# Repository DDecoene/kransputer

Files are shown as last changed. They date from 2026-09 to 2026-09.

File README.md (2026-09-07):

# kransputer

## What Kransputer is

Kransputer is a working computer built from a few thousand discrete CMOS
transistors — a machine on the scale of an Intel 4004, but made of parts you can
hold — designed to grow into a multiprocessor: one core, then a ring of up to
eight, passing messages the way INMOS's Transputer did. It exists to be
understood and rebuilt, by a person, a class or a hackerspace. Not to be sold.

## Why it looks the way it does

One decision forces everything else: CMOS. Almost every discrete-transistor
computer ever built is NMOS and burns about a watt standing still. CMOS costs
twice the transistors but makes power scale with clock rate instead — turn the
clock down and the machine sips. Staying inside a small transistor budget is why
the design is stripped to the bone:

- **One instruction** — subleq only, so there is no decoder. The instruction set
  lives in the assembler as macros.
- **A few bits at a time** — a serial datapath, so the arithmetic unit is a
  handful of adders. You pay in clock cycles, which are cheap.
- **No bus** — memory, display and input all speak SPI over four wires. No
  address bus, no data bus.

On this machine, talking to the core next door is cheaper than reading your own
memory. That is why the ring is the point, not an afterthought.

## How it gets built — from the ground up

The architecture is settled on paper: a SUBLEQ core with a serial datapath and
SPI links, meant to grow into a message-passing ring. What is deliberate is the
direction of the work. Instead of proving the whole machine on an FPGA before
touching a soldering iron, Kransputer is built upward from real gates, one
module at a time.

1. **Gates** — small PCBs, each a fistful of MOSFETs forming one logic function
   (NAND, NOR, NOT …), that plug into a breadboard and share a common bus. This
   is the layer built so far.
2. **Blocks** — those gates wired into the units the design calls for: the serial
   adder that is the whole ALU, the registers, the subleq sequencer and bit
   counter, the SPI interface to memory, the four-wire link to the next core.
   Each block is first modelled in structural Verilog — gate for gate, built
   from the same NAND/NOR/NOT cells as the boards — and checked in simulation,
   then built physically on breadboards.
3. **A core** — one complete processor, assembled from the blocks.
4. **A ring** — the core replicated and connected: two, then four, then eight,
   blocking on the links for synchronisation.

The structural model is the reference: the same stimulus into the simulation and
into the breadboard must give the same result, or the block is wrong.

## Status

The gate boards are drawn but **not yet routed** — schematics and rough
placement are done, copper is not. Work right now is on the first blocks in
structural Verilog, which land here soon. Once those hold up in simulation the
boards get routed and finished for a first self-ordered run, with build notes
and other material alongside.

## This repository

Discrete-logic building blocks for the kransputer — the **Gates** layer above.
Each module is a small PCB that plugs into a breadboard on two opposite edge
headers carrying an identical 16-pin pass-through bus, so modules can sit side by
side across one or more breadboards and be wired together into larger logic.

## Boards

| TARGET | Board |
|---|---|
| `nand` | 4x discrete static-CMOS 2-input NAND |
| `nor` | 4x discrete static-CMOS 2-input NOR |
| `not` | 6x discrete static-CMOS inverter |
| `indicator` | 12-channel buffered bus LED indicator |

Logic FETs are AO3400A (N-channel) / AO3401A (P-channel) in SOT-23.

The logic boards carry **no** indicator parts. Every node is on the bus; the
indicator board buffers each signal with a single AO3400A in common source (its
gate is high-impedance, so the logic net is not loaded) that sinks an LED fed
from the indicator board's own VDD rail. **LED lit = logic 1.** Watching the
machine therefore does not sag the logic levels.

## Bus pinout

Both edge headers (`J1`, `J2`) carry the same 16 pins, wired 1:1, so any signal
is reachable from either edge. Framing is fixed: pin 1 = VDD, pin 2 = GND,
pins 3–14 carry the 12 signal nets the board drives, pins 15/16 are the
edge-to-edge spares (`BUS_X`, `BUS_Y`).

`J1`/`J2` are stacking headers: male tails point down into the breadboard,
female sockets face up so the indicator shield can plug onto the same 16 pins.

### Signal nets per board (bus pins 3–14)

| Pin | `nand` | `nor` | `not` | `indicator` |
|-----|---|---|---|---|
| 3 | NAND_1_A | NOR_1_A | NOT_1_IN | SIG1 |
| 4 | NAND_1_B | NOR_1_B | NOT_1_OUT  | SIG2 |
| 5 | NAND_1_Y | NOR_1_Y | NOT_2_IN | SIG3 |
| 6 | NAND_2_A | NOR_2_A | NOT_2_OUT  | SIG4 |
| 7 | NAND_2_B | NOR_2_B | NOT_3_IN | SIG5 |
| 8 | NAND_2_Y | NOR_2_Y | NOT_3_OUT  | SIG6 |
| 9 | NAND_3_A | NOR_3_A | NOT_4_IN | SIG7 |
| 10  | NAND_3_B | NOR_3_B | NOT_4_OUT  | SIG8 |
| 11  | NAND_3_Y | NOR_3_Y | NOT_5_IN | SIG9 |
| 12  | NAND_4_A | NOR_4_A | NOT_5_OUT  | SIG10 |
| 13  | NAND_4_B | NOR_4_B | NOT_6_IN | SIG11 |
| 14  | NAND_4_Y | NOR_4_Y | NOT_6_OUT  | SIG12 |

The bus is positional: `J1` pin k ≡ `J2` pin k on every board. The indicator
shield taps pins 3–14 as `SIG1..SIG12` and shows whatever a neighbouring board
drives there.

Supply: 5 V on the bus. The two header rows are 0.9" apart (row `a` to row `j`
of one breadboard); columns b–e and f–i stay free for patch wires.

## Build

```bash
python3 -m venv venv
./venv/bin/pip install -r requirements.txt

./venv/bin/python circuit.py             # writes every <target>_module.net
./venv/bin/python circuit.py nand        # or just one
```

`kicad_env.py` finds the KiCad symbol libraries at the macOS bundle path
(`/Applications/KiCad/KiCad.app/...`). On Linux or Windows, set the
`KICAD*_SYMBOL_DIR` / `KICAD*_FOOTPRINT_DIR` environment variables to your
install's library paths before running, or adjust `kicad_env.py`.

1. Turn the netlist into a board. Either open a new PCB project `nand_module/`
   in KiCad and "Update PCB from Netlist", or run `kinet2pcb` headless (needs
   `skidl`, `kinparse` and `pcbnew` on the *same* Python — i.e. installed into
   KiCad's bundled Python, since `pcbnew` is not in the venv):
   ```bash
   kinet2pcb -i nand_module.net -o nand_module/nand_module.kicad_pcb -w --overwrite
   ```
2. Rough auto-placement — run from the folder that contains `nand_module/`,
   using KiCad's bundled Python:
   ```bash
   /Applications/KiCad/KiCad.app/Contents/Frameworks/Python.framework/Versions/3.9/bin/python3 \
       place.py nand
   ```
   `place.py` positions J1/J2 on opposite 0.9" edges, clusters each gate between
   them, draws a tight `Edge.Cuts` rectangle and pours a `B.Cu` GND zone. Pass an
   explicit `.kicad_pcb` path as a second argument to place a board elsewhere.
3. Reopen in KiCad, nudge, route. Re-fill the GND zone. Run DRC.
4. Plot Gerbers.

Repeat with `nor`, `not`, and `indicator` (each is its own KiCad project in its
own `<target>_module/` folder). `nand_module/`, `nor_module/`, `not_module/` and
`indicator_module/` are checked in.

### Fan-out

A discrete gate output driving other **gate** inputs is limited by speed, not
current (CMOS inputs are capacitive) — fine at this machine's speeds. One
indicator-board channel adds roughly the AO3400A gate capacitance to the net it
watches; one indicator board on the bus is negligible.

## Tests

```bash
./venv/bin/pytest
```

The placement integration test is skipped unless `kinet2pcb` can import
`pcbnew` (it cannot from the venv). `place.py` uses fixed, hand-computed
coordinates per board type, so its output is deterministic and easy to
eyeball in KiCad.

## Layout

- `circuit.py`  — SKiDL netlist generator (all boards, no arg = build every one)
- `place.py`    — pcbnew layout: exact positions per board type, Edge.Cuts, GND pour
- `kicad_env.py`— points SKiDL at the bundled KiCad libraries on macOS
- `SYMBOLS.md`  — resolved KiCad symbols (AO3400A/AO3401A, LED, R array, header)
- `tests/`      — SKiDL-netlist topology checks per board + CLI + place integration

## Licence

[PolyForm Noncommercial License 1.0.0](LICENSE). Build it, study it, modify it,
teach with it, and contribute — freely, for any noncommercial purpose. Selling
kits, boards, or hardware based on this work is reserved to the maintainer; see
[COMMERCIAL.md](COMMERCIAL.md). Contribution terms are in
[CONTRIBUTING.md](CONTRIBUTING.md).

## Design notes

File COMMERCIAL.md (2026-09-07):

# Commercial use

This project is released under the [PolyForm Noncommercial License 1.0.0](LICENSE).
You may build, study, modify, teach with, and contribute to it freely for any
**noncommercial** purpose.

**Commercial use is reserved to the maintainer, Dennis Decoene.** This includes,
but is not limited to:

- selling kits, bare PCBs, panels, or assembled boards or machines based on this
  work;
- selling this work bundled with other hardware or as part of a paid product;
- paid services whose main deliverable is this work or a derivative of it.

If you want to do any of the above, contact the maintainer for a separate
commercial licence: open an issue on
<https://github.com/DDecoene/kransputer> or reach out directly.

## What is *not* commercial use

These are fine under the noncommercial licence, no permission needed:

- a person, class, hackerspace, or club building boards for their own use or for
  teaching;
- recovering the actual cost of materials (PCB fab, parts, shipping) when you
  build boards for others in a non-profit setting;
- a school, university, public research or public-safety organisation using the
  work, regardless of how that organisation is funded.

If you are not sure which side of the line you are on, ask first.

## Name

"Kransputer" is the maintainer's name for this project. A fork may use the code
and designs under the licence, but not the Kransputer name to market kits or
hardware.

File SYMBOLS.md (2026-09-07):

# Resolved KiCad symbols and footprints

Verified 2026-09-06 against KiCad 10.0.6 bundled libraries; AO parts added
2026-09-07.

## Transistors

| Part | Symbol | Footprint | Pins (num, name) |
|---|---|---|---|
| AO3401A | `Transistor_FET:AO3401A`  | `Package_TO_SOT_SMD:SOT-23` | 1=G, 2=S, 3=D |
| AO3400A | `Transistor_FET:AO3400A`  | `Package_TO_SOT_SMD:SOT-23` | 1=G, 2=S, 3=D |

`AO3401A` (P-channel, `FET_P` in `circuit.py`) `extends TP0610T`; `AO3400A`
(N-channel, `FET_N`) `extends Q_NMOS_GSD`. Both resolve to pin 1=G, 2=S, 3=D,
matching the SOT-23 footprint — identical to the BSS84/BSS138 they replaced, so
the `part["G"/"S"/"D"]` name lookups are unchanged.

`value` is `"AO3401A"` / `"AO3400A"` out of the symbol; do not pass `value=`.

## LED

`Device:LED` on `LED_SMD:LED_0805_2012Metric`. Pins: 1=K, 2=A.

## LED series resistor array (indicator board)

**There is no 3x resistor-array footprint in KiCad 10.** Nearest is `4x0603`.
So the indicator board uses one **4-element** array per group of 3 channels, with
the 4th resistor unused (both pins tied to GND — no current, no floating-pad DRC).

- Footprint: `Resistor_SMD:R_Array_Convex_4x0603` (8 pads)
- Symbol:    `Device:R_Pack04` (8 pins, 4 isolated resistors)
- Pin map: R1 = 1 & 8, R2 = 2 & 7, R3 = 3 & 6, R4 = 4 & 5
- LED-anode side = pads 1/2/3 (one physical edge), VDD side = pads 8/7/6
- `_RARRAY_PAIRS = [("1", "8"), ("2", "7"), ("3", "6")]`  (the 3 channels of the group)
- Spare: `("4", "5")` both to GND

## 16-pin bus header

- Footprint: `Connector_PinHeader_2.54mm:PinHeader_1x16_P2.54mm_Vertical`
- Symbol:    `Connector:Conn_01x16_Pin`
- Pins: num `"1"`..`"16"`, name `"Pin_1"`..`"Pin_16"`
- Integer indexing (`j[8]`) resolves by pin number.

## Bulk cap

`Device:C` on `Capacitor_SMD:C_0805_2012Metric`. Pins 1, 2.

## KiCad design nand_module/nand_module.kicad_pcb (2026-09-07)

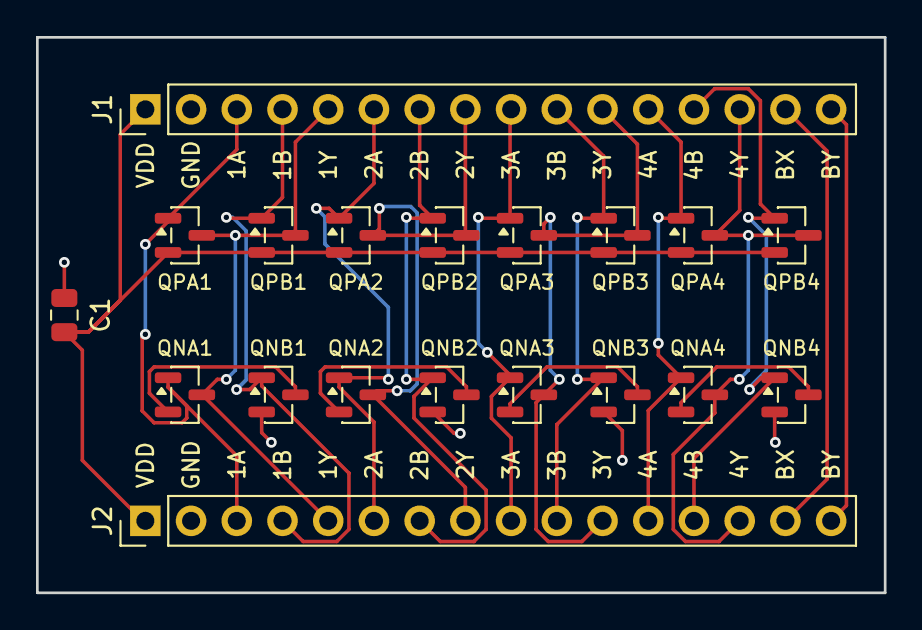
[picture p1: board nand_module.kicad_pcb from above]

Board: 2 copper layers, 47.1 x 30.9 mm, 19 parts (0 on the bottom side), 20 nets.

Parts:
C1: 1u; C_0805_2012Metric
J1, J2: BUS_STACK_1x16; PinHeader_1x16_P2.54mm_Vertical
QNA1, QNA2, QNA3, QNA4: AO3400A; SOT-23
QNB1, QNB2, QNB3, QNB4: AO3400A; SOT-23
QPA1, QPA2, QPA3, QPA4: AO3401A; SOT-23
QPB1, QPB2, QPB3, QPB4: AO3401A; SOT-23

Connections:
BUS_X: J1.15, J2.15
BUS_Y: J1.16, J2.16
GND: C1.2, J1.2, J2.2, QNB1.2, QNB2.2, QNB3.2, QNB4.2
NAND_1_A: J1.3, J2.3, QNA1.1, QPA1.1
NAND_1_B: J1.4, J2.4, QNB1.1, QPB1.1
NAND_1_MID: QNA1.2, QNB1.3
NAND_1_Y: J1.5, J2.5, QNA1.3, QPA1.3, QPB1.3
NAND_2_A: J1.6, J2.6, QNA2.1, QPA2.1
NAND_2_B: J1.7, J2.7, QNB2.1, QPB2.1
NAND_2_MID: QNA2.2, QNB2.3
NAND_2_Y: J1.8, J2.8, QNA2.3, QPA2.3, QPB2.3
NAND_3_A: J1.9, J2.9, QNA3.1, QPA3.1
NAND_3_B: J1.10, J2.10, QNB3.1, QPB3.1
NAND_3_MID: QNA3.2, QNB3.3
NAND_3_Y: J1.11, J2.11, QNA3.3, QPA3.3, QPB3.3
NAND_4_A: J1.12, J2.12, QNA4.1, QPA4.1
NAND_4_B: J1.13, J2.13, QNB4.1, QPB4.1
NAND_4_MID: QNA4.2, QNB4.3
NAND_4_Y: J1.14, J2.14, QNA4.3, QPA4.3, QPB4.3
VDD: C1.1, J1.1, J2.1, QPA1.2, QPA2.2, QPA3.2, QPA4.2, QPB1.2, QPB2.2, QPB3.2, QPB4.2

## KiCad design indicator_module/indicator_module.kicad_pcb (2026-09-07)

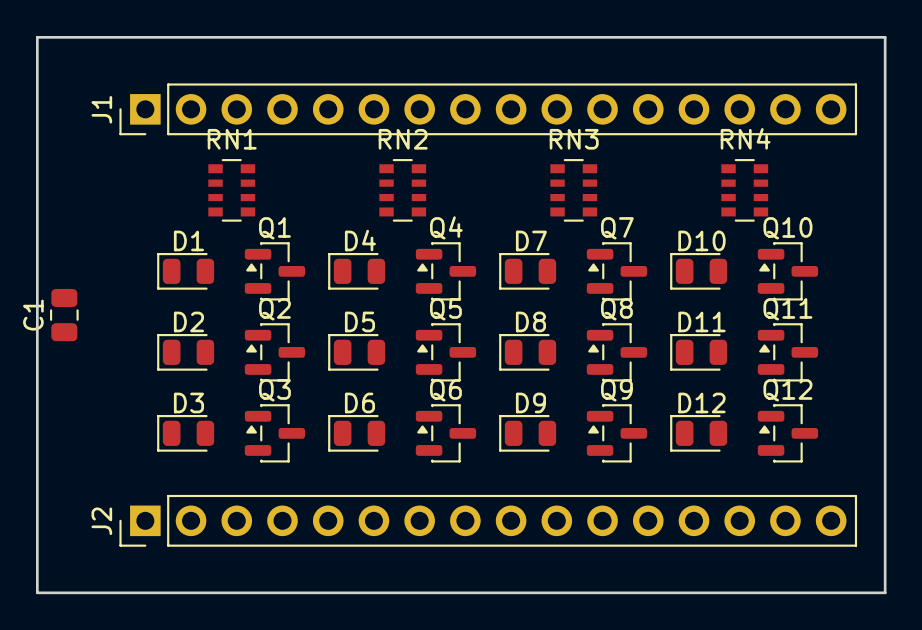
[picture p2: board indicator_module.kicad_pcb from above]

Board: 2 copper layers, 47.1 x 30.9 mm, 31 parts (0 on the bottom side), 40 nets, no tracks yet.

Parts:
C1: 1u; C_0805_2012Metric
D1: D1; LED_0805_2012Metric
D2: D2; LED_0805_2012Metric
D3: D3; LED_0805_2012Metric
D4: D4; LED_0805_2012Metric
D5: D5; LED_0805_2012Metric
D6: D6; LED_0805_2012Metric
D7: D7; LED_0805_2012Metric
D8: D8; LED_0805_2012Metric
D9: D9; LED_0805_2012Metric
D10: D10; LED_0805_2012Metric
D11: D11; LED_0805_2012Metric
D12: D12; LED_0805_2012Metric
J1, J2: BUS_STACK_1x16; PinHeader_1x16_P2.54mm_Vertical
Q1, Q2, Q3, Q4, Q5, Q6, Q7, Q8, Q9, Q10, Q11, Q12: AO3400A; SOT-23
RN1, RN2, RN3, RN4: 1k; R_Array_Convex_4x0603

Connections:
BUS_X: J1.15, J2.15
BUS_Y: J1.16, J2.16
GND: C1.2, J1.2, J2.2, Q1.2, Q2.2, Q3.2, Q4.2, Q5.2, Q6.2, Q7.2, Q8.2, Q9.2, Q10.2, Q11.2, Q12.2, RN1.4, RN1.5, RN2.4, RN2.5, RN3.4, RN3.5, RN4.4, RN4.5
unnamed: D1.1, Q1.3
unnamed: D1.2, RN1.1
unnamed: D2.1, Q2.3
unnamed: D2.2, RN1.2
unnamed: D3.1, Q3.3
unnamed: D3.2, RN1.3
unnamed: D4.1, Q4.3
unnamed: D4.2, RN2.1
unnamed: D5.1, Q5.3
unnamed: D5.2, RN2.2
unnamed: D6.1, Q6.3
unnamed: D6.2, RN2.3
unnamed: D7.1, Q7.3
unnamed: D7.2, RN3.1
unnamed: D8.1, Q8.3
unnamed: D8.2, RN3.2
unnamed: D9.1, Q9.3
unnamed: D9.2, RN3.3
unnamed: D10.1, Q10.3
unnamed: D10.2, RN4.1
unnamed: D11.1, Q11.3
unnamed: D11.2, RN4.2
unnamed: D12.1, Q12.3
unnamed: D12.2, RN4.3
SIG1: J1.3, J2.3, Q1.1
SIG2: J1.4, J2.4, Q2.1
SIG3: J1.5, J2.5, Q3.1
SIG4: J1.6, J2.6, Q4.1
SIG5: J1.7, J2.7, Q5.1
SIG6: J1.8, J2.8, Q6.1
SIG7: J1.9, J2.9, Q7.1
SIG8: J1.10, J2.10, Q8.1
SIG9: J1.11, J2.11, Q9.1
SIG10: J1.12, J2.12, Q10.1
SIG11: J1.13, J2.13, Q11.1
SIG12: J1.14, J2.14, Q12.1
VDD: C1.1, J1.1, J2.1, RN1.6, RN1.7, RN1.8, RN2.6, RN2.7, RN2.8, RN3.6, RN3.7, RN3.8, RN4.6, RN4.7, RN4.8

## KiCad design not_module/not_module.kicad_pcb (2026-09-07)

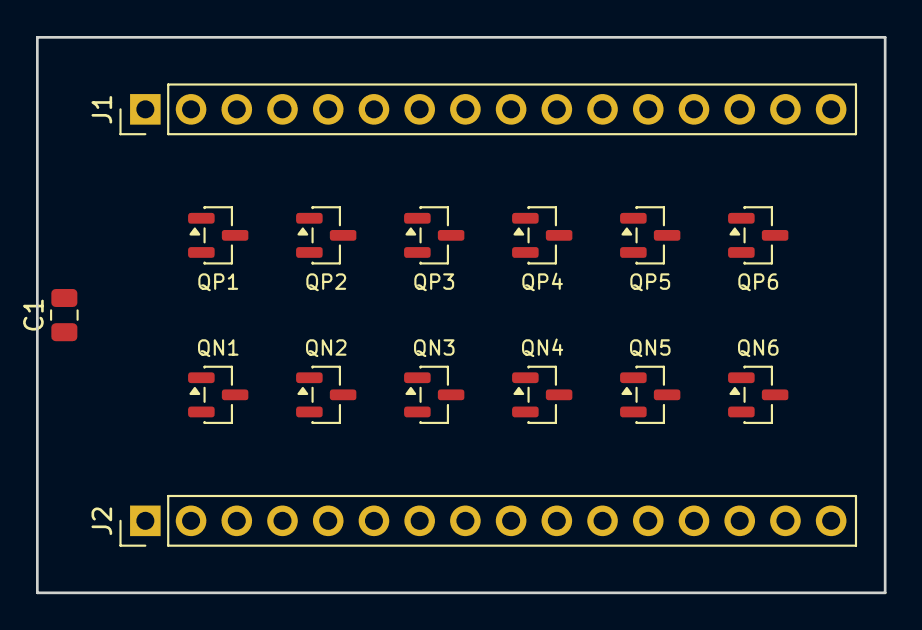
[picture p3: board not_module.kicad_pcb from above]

Board: 2 copper layers, 47.1 x 30.9 mm, 15 parts (0 on the bottom side), 16 nets, no tracks yet.

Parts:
C1: 1u; C_0805_2012Metric
J1, J2: BUS_STACK_1x16; PinHeader_1x16_P2.54mm_Vertical
QN1, QN2, QN3, QN4, QN5, QN6: AO3400A; SOT-23
QP1, QP2, QP3, QP4, QP5, QP6: AO3401A; SOT-23

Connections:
BUS_X: J1.15, J2.15
BUS_Y: J1.16, J2.16
GND: C1.2, J1.2, J2.2, QN1.2, QN2.2, QN3.2, QN4.2, QN5.2, QN6.2
NOT_1_IN: J1.3, J2.3, QN1.1, QP1.1
NOT_1_OUT: J1.4, J2.4, QN1.3, QP1.3
NOT_2_IN: J1.5, J2.5, QN2.1, QP2.1
NOT_2_OUT: J1.6, J2.6, QN2.3, QP2.3
NOT_3_IN: J1.7, J2.7, QN3.1, QP3.1
NOT_3_OUT: J1.8, J2.8, QN3.3, QP3.3
NOT_4_IN: J1.9, J2.9, QN4.1, QP4.1
NOT_4_OUT: J1.10, J2.10, QN4.3, QP4.3
NOT_5_IN: J1.11, J2.11, QN5.1, QP5.1
NOT_5_OUT: J1.12, J2.12, QN5.3, QP5.3
NOT_6_IN: J1.13, J2.13, QN6.1, QP6.1
NOT_6_OUT: J1.14, J2.14, QN6.3, QP6.3
VDD: C1.1, J1.1, J2.1, QP1.2, QP2.2, QP3.2, QP4.2, QP5.2, QP6.2

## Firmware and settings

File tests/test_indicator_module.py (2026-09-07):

import circuit
from skidl import Net
from helpers import circuit as active_circuit, net_by_name, pins_named, pins_numbered


def _one_group():
    s1, s2, s3 = Net("SIG1"), Net("SIG2"), Net("SIG3")
    vdd, gnd = Net("VDD"), Net("GND")
    circuit.indicator_gate(1, s1, s2, s3, vdd, gnd)


def _part(ref):
    return next(p for p in active_circuit().parts if p.ref == ref)


def test_indicator_group_parts():
    _one_group()
    refs = {p.ref for p in active_circuit().parts}
    assert {"Q1", "Q2", "Q3"} <= refs   # buffer FETs, running index
    assert {"D1", "D2", "D3"} <= refs   # LEDs
    assert "RN1" in refs                # resistor array for the group
    led = _part("D1")
    assert led.value == "D1"
    assert led.footprint == circuit.FP_LED
    assert _part("Q1").value == "AO3400A"


def test_indicator_group_channel_topology():
    _one_group()
    # AO3400A common source: source -> GND, gate -> bus signal
    assert ("Q2", "G") in pins_named(net_by_name("SIG2"))
    assert ("Q2", "S") in pins_named(net_by_name("GND"))
    # LED cathode ties to the FET drain (private net)
    d, q = _part("D2"), _part("Q2")
    assert d["K"].net is q["D"].net
    assert d["K"].net.name not in ("VDD", "GND", "SIG2")
    # LED anode goes to the array
    assert ("RN1", "2") in pins_named(d["A"].net) or \
           ("RN1", "2") in pins_numbered(d["A"].net)


def test_indicator_group_array_feeds_vdd_and_parks_spare():
    _one_group()
    vdd = pins_numbered(net_by_name("VDD"))
    gnd = pins_numbered(net_by_name("GND"))
    assert {("RN1", "8"), ("RN1", "7"), ("RN1", "6")} <= vdd   # 3 channels VDD side
    assert {("RN1", "4"), ("RN1", "5")} <= gnd                 # spare R4 parked


def test_second_group_continues_the_running_index():
    s4, s5, s6 = Net("SIG4"), Net("SIG5"), Net("SIG6")
    vdd, gnd = Net("VDD"), Net("GND")
    circuit.indicator_gate(2, s4, s5, s6, vdd, gnd)
    refs = {p.ref for p in active_circuit().parts}
    assert {"Q4", "Q5", "Q6", "D4", "D5", "D6", "RN2"} <= refs
    assert ("Q5", "G") in pins_named(net_by_name("SIG5"))


def test_assemble_indicator_module_counts():
    circuit.assemble_indicator_module()
    parts = active_circuit().parts
    assert len([p for p in parts if p.value == "AO3400A"]) == 12
    assert len([p for p in parts if p.footprint == circuit.FP_LED]) == 12
    assert sorted(p.ref for p in parts if p.ref.startswith("RN")) == \
        ["RN1", "RN2", "RN3", "RN4"]
    assert sorted((p.ref for p in parts if p.ref.startswith("D")),
                  key=lambda r: int(r[1:])) == [f"D{i}" for i in range(1, 13)]
    assert {p.ref for p in parts if p.ref.startswith("J")} == {"J1", "J2"}
    assert [p.ref for p in parts if p.ref == "C1"] == ["C1"]
    assert not [p for p in parts if p.value == "AO3401A"]


def test_assemble_indicator_module_bus_reaches_buffers():
    circuit.assemble_indicator_module()
    j1 = next(p for p in active_circuit().parts if p.ref == "J1")
    assert j1[10].net.name == "SIG8"                    # bus pin 10 -> SIG(10-2)
    assert ("Q8", "G") in pins_named(net_by_name("SIG8"))


def test_build_indicator_module_writes_netlist(tmp_path, monkeypatch):
    monkeypatch.chdir(tmp_path)
    circuit.build_indicator_module()
    assert (tmp_path / "indicator_module.net").exists()

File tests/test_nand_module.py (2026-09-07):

import re

import circuit
from skidl import Net
from helpers import circuit as active_circuit, net_by_name, pins_named, pins_numbered


def _one_gate():
    a, b, y = Net("NAND_1_A"), Net("NAND_1_B"), Net("NAND_1_Y")
    vdd, gnd = Net("VDD"), Net("GND")
    circuit.nand_gate(1, a, b, y, vdd, gnd)


def test_nand_gate_has_four_semantic_transistors():
    _one_gate()
    parts = active_circuit().parts
    refs = {p.ref for p in parts}
    assert refs == {"QPA1", "QPB1", "QNA1", "QNB1"}
    vals = {p.ref: p.value for p in parts}
    assert vals["QPA1"] == "AO3401A"
    assert vals["QNA1"] == "AO3400A"


def test_nand_gate_topology():
    _one_gate()
    assert pins_named(net_by_name("NAND_1_A")) == {("QPA1", "G"), ("QNA1", "G")}
    assert pins_named(net_by_name("NAND_1_B")) == {("QPB1", "G"), ("QNB1", "G")}
    assert pins_named(net_by_name("VDD")) == {("QPA1", "S"), ("QPB1", "S")}
    assert pins_named(net_by_name("NAND_1_Y")) == {
        ("QPA1", "D"), ("QPB1", "D"), ("QNA1", "D")}
    assert pins_named(net_by_name("NAND_1_MID")) == {
        ("QNA1", "S"), ("QNB1", "D")}
    assert pins_named(net_by_name("GND")) == {("QNB1", "S")}


def test_nand_gate_footprints_are_sot23():
    _one_gate()
    assert all(p.footprint == circuit.FP_SOT23
               for p in active_circuit().parts)


def test_assemble_nand_module_part_counts():
    circuit.assemble_nand_module()
    parts = active_circuit().parts
    assert len([p for p in parts if p.value == "AO3401A"]) == 8
    assert len([p for p in parts if p.value == "AO3400A"]) == 8
    assert {p.ref for p in parts if p.ref.startswith("J")} == {"J1", "J2"}
    assert [p.ref for p in parts if p.ref == "C1"] == ["C1"]
    assert not [p for p in parts if p.value == "LED"]


def test_assemble_nand_module_bus_wiring():
    circuit.assemble_nand_module()
    j1 = next(p for p in active_circuit().parts if p.ref == "J1")
    assert j1[5].net.name == "NAND_1_Y"
    assert j1[8].net.name == "NAND_2_Y"
    assert j1[14].net.name == "NAND_4_Y"
    assert pins_numbered(net_by_name("BUS_X")) == {("J1", "15"), ("J2", "15")}


def test_assemble_nand_module_bulk_cap_across_rails():
    circuit.assemble_nand_module()
    assert ("C1", "1") in pins_numbered(net_by_name("VDD"))
    assert ("C1", "2") in pins_numbered(net_by_name("GND"))


def test_build_nand_module_writes_netlist(tmp_path, monkeypatch):
    monkeypatch.chdir(tmp_path)
    circuit.build_nand_module()
    out = tmp_path / "nand_module.net"
    assert out.exists()
    comps = re.findall(r"\(comp\s", out.read_text())
    assert len(comps) == 19   # 16 FET + C1 + J1 + J2

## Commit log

2026-09-06 Baseline: SKiDL netlist-generator en pcbnew-plaatsingsscript
    circuit.py genereert de KiCad-netlist voor de logic-gates, place.py
    doet grove auto-plaatsing in pcbnew. Uitgangspunt voor de herstructurering
    naar bus-modules (zie ontwerp-spec in kransputer-notes).
2026-09-06 test: add pytest infrastructure and SKiDL inspection helpers
    kicad_env.py extracts the macOS KiCad library-path fix so it can run
    before skidl is imported (conftest needs skidl at collection time).
2026-09-06 docs: resolve resistor-array and bus-header symbols
    No 3x resistor-array footprint exists in KiCad 10; indicator board uses
    one 4x0603 array per gate with the 4th element parked on GND.
2026-09-06 feat: 16-pin pass-through bus and edge headers
    circuit.py rewritten from the top: kicad_env import, tool select, bus
    pinout list, add_bus_headers() wiring J1/J2 identically.
2026-09-06 feat: discrete static-CMOS NAND gate subcircuit
    nand_gate(inst, ...) with semantic transistor refs. nor_gate/inverter
    kept from baseline for the future NOR/NOT specs, not wired.
2026-09-06 feat: assemble and build the NAND module netlist
    assemble_nand_module wires 4x nand_gate + bulk cap to the bus;
    build_nand_module writes nand_module.net (19 components).
2026-09-06 feat: buffered LED indicator module
    indicator_gate: one BSS138 common-source LED driver per bus signal,
    fed from VDD through a 4x0603 array (spare element parked on GND).
    assemble/build_indicator_module -> indicator_module.net.
2026-09-06 feat: TARGET dispatch and CLI entry point
    python circuit.py [nand|indicator] -> <target>_module.net; unknown
    target exits non-zero.
2026-09-06 feat: pure placement geometry helpers
    grid_positions, bus_row_ys, header_pin_xs, outline_rect, natural_key,
    group_by_sheet - no pcbnew dependency, unit-tested.
2026-09-06 feat: pcbnew placement for bus modules with Edge.Cuts outline
    place.py positions J1/J2 on opposite rows, clusters subcircuits between
    them, parks leftovers, draws a tight Edge.Cuts rectangle. Verified under
    KiCad 10 bundled Python on a synthetic 19-footprint board. Integration
    test skips when kinet2pcb cannot import pcbnew (venv has no pcbnew).
2026-09-06 feat: circuit.py with no argument builds every module netlist
    reset() between builds so each netlist starts from a clean circuit.
    An explicit target still builds just that one.
2026-09-06 fix: deterministic per-board layout in place.py
    The generic sheet-grid overlapped footprints, dropped C1 on top of a
    transistor, and ran clusters past the bottom header. Replaced with
    exact hand-computed coordinates per board type:
    - headers rotated so the 16 pins run along X, 0.9" apart
    - NAND: 2x2 SOT-23 per gate, centred on the gate's bus pins
    - indicator: RN array + LED|FET rows per gate
    - C1 parked left of pin 1; Edge.Cuts hugs the header span
    Verified on real footprints: 0 pad overlaps, min gap 0.95 mm, board
    47 x 31 mm. placement.py and its tests removed (no longer used).
2026-09-06 add generated NAND and indicator board projects (placed, unrouted)
    kinet2pcb turns <target>_module.net into <target>_module.kicad_pcb;
    place.py then lays it out. Committed as a recoverable baseline before
    routing. .kicad_prl (local UI state) stays untracked.
    [indicator_module.kicad_pcb, nand_module.kicad_pcb]
2026-09-06 Route NAND module (2-layer, top)
    [nand_module.kicad_pcb]
2026-09-06 Shorten component refs: drop redundant NAND_ prefix
    NAND_<n>_QPB -> QPB_<n>, indicator NAND_<n>_A -> A_<n>, NAND_<n>_QA -> QA_<n>
    (RN<n> unchanged). Board is all-NAND so the prefix was noise on the
    silkscreen and made labels overlap. Generator + placement + tests only;
    board files not touched.
    [test_indicator_module.py, test_nand_module.py]
2026-09-06 Add rename_refs.py: bulk-rename board refs to the short scheme
    pcbnew script that rewrites NAND_<n>_QPA etc. to QPA_<n> on an existing
    placed/routed board. Touches only the Reference/Value fields; tracks,
    vias, zones, positions and net names are left untouched. Idempotent.
    Verified on the routed NAND board: 15 refs renamed, 240 segments and all
    net names preserved.
2026-09-06 Rename NAND board refs to short scheme; drop rename_refs.py
    Ran rename_refs.py (kept in history at fabc05a) over the routed board:
    NAND_<n>_QP*/QN* -> QP*_<n>/QN*_<n>. 240 track objects and all net
    names verified unchanged. Also captures routing progress (211 segments).
    [nand_module.kicad_pcb]
2026-09-06 Add silkscreen pin labels to NAND board; drop label_headers.py
    Ran label_headers.py (kept in history) over the routed board: 28 F.Silks
    labels (VDD/GND + 1A..4Y) inside both edge headers. 240 track objects,
    refs and net names verified unchanged.
    [nand_module.kicad_pcb]
2026-09-06 Add label_headers.py: silkscreen pin labels for the bus headers
    pcbnew script: writes VDD/GND and <group><sig> (1A..4Y) on F.Silkscreen
    just inside each edge header for pins 1-14. Idempotent; touches only
    silk text. Kept in history for reuse; removed from the tree next commit.
2026-09-06 Drop underscore from short refs (QPA_1 -> QPA1); tidy ref text
    place.py now parks each NAND transistor's reference text in the gap
    between the pull-up and pull-down rows at 0.8 mm so it clears the
    header pin labels. Generator + tests follow the QPA1 form.
    [test_indicator_module.py, test_nand_module.py]
2026-09-06 Add tidy_labels.py: drop ref underscores + reposition NAND ref text
    One-shot pcbnew script for an existing board. Kept in history; removed
    from the tree next commit.
2026-09-06 Tidy NAND board labels: QPA1 form + ref text off the pin labels
    Ran tidy_labels.py (in history) over the routed board: 16 refs
    QPA_1->QPA1 etc., their reference text moved into the central gap at
    0.8 mm. 240 track objects and all net names unchanged.
    [nand_module.kicad_pcb]
2026-09-06 Add label_headers.py: header pin labels incl. BX/BY spares
    pcbnew script writing VDD/GND, 1A..4Y and BX/BY on F.Silkscreen for all
    16 pins of both edge headers. Reads pad coords before mutating (SWIG
    proxy safety). Kept in history; removed next commit.
2026-09-06 Label the two spare bus pins (BX/BY) on both headers
    Reran label_headers.py over the board: silk labels 28 -> 32 (BX/BY added
    at pins 15/16). 240 track objects, refs and net names unchanged.
    [nand_module.kicad_pcb]
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2026-09-07 Add claude-project-bundler config
    Bundles every tracked repo file (scripts, tests, docs, KiCad projects)
    and mirrors .gitignore for exclusions (venv, caches, SKiDL/KiCad
    generated output, fab/, backups). Run: npx claude-project-bundler bundle .
    Output in cpb-output/ (gitignored).
2026-09-07 Treat .kicad_pcb as binary in the bundle (listed, no content)
    Board files stay in the file list as [Binary file] placeholders instead
    of ~400 KB of track coordinates. Bundle drops from 462 KB to 55 KB.
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2026-09-07 Add nor_module and not_module KiCad board projects
    Netlist -> kinet2pcb -> place.py: 19 / 15 footprints, headers on 0.9in
    rows, tight Edge.Cuts, B.Cu ground pour. Same 47.1 x 30.9 mm outline as
    the NAND board.
    [nor_module.kicad_pcb, not_module.kicad_pcb]
2026-09-07 Sync docs with AO-series refactor and nor/not boards
    - SYMBOLS.md: AO3400A/AO3401A replace BSS138/BSS84
    - place.py docstring: list all four targets
    - README: kinet2pcb build step, place.py pours GND, module dirs checked in
2026-09-07 Relabel nand/indicator board FETs BSS -> AO34xxA (value text only)
    AO3400A/AO3401A are pin-compatible SOT-23 drop-ins for BSS138/BSS84, so only
    the silkscreen Value changes. Routing (nand: 211 segments, 29 vias, GND zone),
    placement and labels untouched. Boards verified to load in pcbnew.
    [indicator_module.kicad_pcb, nand_module.kicad_pcb]
2026-09-07 Regenerate indicator board from current netlist
    Was stale (NAND_* nets, NAND_n_QA refs, BSS138). Now SIG1..SIG12 nets,
    D1..D12 / Q1..Q12 refs, AO3400A. Unrouted board, no manual work lost.
    [indicator_module.kicad_pcb]
2026-09-07 Sync nand board header value to BUS_STACK_1x16
    Last remaining divergence from the netlist (J1/J2 were BUS_A/BUS_B).
    Refs, nets and FET values already matched. Routing untouched: 211
    segments, 29 vias, GND zone; verified in pcbnew.
    [nand_module.kicad_pcb]
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2026-09-07 README: correct build-method section and add status
    The build-method section claimed a settled Python model / emulator kept as
    the reference. No such model exists. Rewrite it: each block is modelled in
    structural Verilog, gate for gate, and checked in simulation before it is
    built on breadboards.
    Add a Status section: the gate boards are drawn but not yet routed; current
    work is the first structural-Verilog blocks.
